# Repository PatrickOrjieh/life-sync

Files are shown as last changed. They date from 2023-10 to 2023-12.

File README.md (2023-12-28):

# Aerosense Project

## About Aerosense

Aerosense is a 3rd year Universal Design Project, focused at improving daily living for individuals with asthma through universal design principles. Moving from wearable to portable, Aerosense is an air quality monitor that provides real-time data, historical analytics, and health insights directly to users' smartphones.

## Features

- **Real-Time Monitoring**: Tracks PM2.5, PM10, VOCs, and other air quality measurements.
- **Portability**: Designed for on-the-go use without compromising functionality.
- **Mobile App**: Real-time data and historical trends.
- **Personalized Notifications**: (Buggy) Alerts tailored to individual health profiles.
- **Educational Content**: Understand the impact of air quality on health.
- **GPS Mapping**: Identify and avoid areas with poor air quality.

## Universal Design

The Aerosense project uses the principles of universal design, ensuring accessibility and ease of use for all users, regardless of age, ability, or asthma severity. We have conducted extensive user testing to refine the user interface and experience, making sure that the information is not only accessible but also actionable (future enhancements).

## User Testing and Evaluation
User testing was a crucial part of our development process. We used the think-aloud protocol, to gather  data on our system's usability and functionality. Our testers, including Seun (a first-year Business student with asthma),James and Tom , provided invaluable feedback that will directly influence the final design and features.

## Test Documentation
Our test documentation includes detailed test cases that cover both UI interactions and user experiences. We have recorded the testing process, issues encountered, and positive aspects noted by the testers.

## Project Code
The project code can be found in the link - `https://github.com/PatrickOrjieh/air-quality-monitor`

## Update to About Section

**Previous:**
"Universal design project focused on creating a wearable air quality monitor tailored for asthma patients. Integrates with a mobile app for real-time alerts and analysis."

**New:**
"A universal design project, Aerosense offers a portable air quality monitoring solution that helps individuals with asthma through actionable environmental insights, supported by an intuitive mobile application."

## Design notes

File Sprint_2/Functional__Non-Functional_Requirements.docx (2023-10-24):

Functional Requirements

1. Air Quality Measurement:
  - The device shall measure and detect particulate matter levels using the PMS7003 sensor.
  - The device shall measure volatile organic compounds and other harmful gases using the BME680 sensor array.

Still reconsidering the location addition at the moment.

2. GPS Integration:
  - The device shall identify and record the user's real-time location using the Neo 6m/Grove GPS.
  - It should timestamp air quality measurements with the respective GPS location.
3. User Alerts on the Wristband:
  - The wristband shall trigger a vibration and sound alert if detected air quality levels surpass predefined hazardous thresholds.
  - The wristband shall exhibit a light to indicate the severity of the air quality (green for good, yellow for moderate, red for poor).
4. Mobile Phone Notifications:
  - In the event of a hazardous air quality detection, a notification shall be sent to the connected mobile phone detailing the air quality measurements.
  - The mobile app shall display levels of particulate matter, VOCs, and maybe current GPS coordinates.
5. Data Storage:
  - Air quality measurements, timestamps, and locations for at least the previous 48 hours shall be stored on the mobile application.
  - Users shall have an option on the app to reset or clear this stored data.
6. Battery Status:
  - The mobile app shall display the current battery level of the wristband.
  - It should notify the user when the battery level goes below a certain threshold.

Non-Functional Requirements:

1. Usability:
  - The wristband should minimize physical interaction, with the mobile app serving as the primary interface for detailed information.
  - Alerts and notifications should be easily distinguishable and understandable.
2. Portability:
  - The device should be lightweight and comfortable for daily wear.
  - It should have a design that is aesthetically pleasing and suitable for various environments (work, sport, casual).
3. Battery Life:
  - The wristband should operate for at least 48 hours on a full charge, considering minimal interactions.
4. Accuracy:
  - Air quality measurements should have an error margin of less than 5%.
  - If using location then GPS coordinates should be accurate to within 10 meters.
5. Durability & Robustness:
  - The wristband should be resistant to everyday wear and tear.
  - It should be splash-proof to handle minor exposures to water.
6. Response Time:
  - The device should relay air quality measurements to the mobile app with a delay of no more than 5 seconds.
  - Alerts should be triggered on the wristband within 5 seconds of a hazardous threshold being detected.
7. Compatibility:
  - The wristband's connected app should be compatible with major mobile OS.
8. Scalability:
  - Future versions should allow for easy integration of additional sensors or features without a complete overhaul of the system.

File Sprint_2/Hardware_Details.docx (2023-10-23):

Sensor Research

PMS7003 - which detects particulate matter in the air which can detect particles of size PM10, PM2.5, PM1 and PM0.3. The PM5003 was rejected as it is too large to be considered for a wearable device. The ENS160 is smaller than the chosen sensor but only measured PM10 and PM2.5.

BME680 - senses VOCs (volatile total compounds) which contribute to air quality. The reviews for this were consistently high across a number of different websites. The SGP30 was also considered however the response time is 2s whereas the BME680 is 1s.

Air530 – location tracker which has low power usage and a good update rate between 1 and 10Hz. The Adafruit Ultimate GPS was a strong competitor with slightly lower power usage and the position accuracy was higher, however was over twice the price of the Air530. In an effort to keep the cost down the Air530 was chosen as it still provided a high tracking sensitivity and plenty of supporting documents.

Hardware Purchased | Price (excluding shipping & VAT)
PMS7003 | 23.05
BME680 | 21.77
Air530 | 12.56
Pi Zero 2 W | 19.58
Vibrating mini motor disc | 1.96
575 ultimate resistor kit | 6.91
Full size breadboard | 5.76
LDR 5 pack | 2.30
Female/male jumper wires | 1.96
Female/female jumper wires | 1.96
Male/male jumper wires | 1.96

Total: €99.77

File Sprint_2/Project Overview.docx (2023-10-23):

Wristband Air Quality Monitor for Asthma Patients

Executive Summary:

Urban living brings with it a lot of air pollutants. Our mission? To make a wrist worn gadget for asthma patients. This tool will gauge the surrounding air quality, providing them with real-time updates. It's more than just a device; it's about giving people the knowledge they need to dodge potential asthma attack.

Objective:

To design, develop, and test a wristband that monitors real-time air quality, providing asthma patients with alerts about environments that may trigger respiratory issues.

Background:

Ask anyone with asthma, and they'll tell you: certain pollutants can feel like invisible enemies. Having information on air quality would be of great benefit. With this wristband, we're not just offering data. We're offering peace of mind.

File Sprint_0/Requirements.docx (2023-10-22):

Functional Requirements:

1. Monitoring Heart Activity:

- The band should always track the wearer's heartbeat using a light-based sensor.
- An alert is necessary if the heart rate goes beyond a set limit, showing potential strain.

2. Tracking Oxygen Levels:

- The band needs to check the amount of oxygen in the user's bloodstream.
- Alerts should be sent if the oxygen count falls under a safe limit.

3. Personal Information Entry:

- Users can input details such as age, weight, height, and workout aims like losing weight, bulking up muscles.
- Using this info, the band or its paired app should suggest tailored exercises.

4. Instant Responses:

- Vibrations or on-screen notifications should be given by the band, depending on heart activity and oxygen counts.
- Messages like "Ease up", "Time for a short rest", or "Push just a bit harder" could be displayed.

5. Exercise Time Keeper:

- An in-built clock in the band should measure each exercise period.
- It's essential for users to have control over this clock: starting, pausing, as needed.

6. Syncing with Smartphone App:

- Bluetooth should link the band with an app on the phone.
- This app is meant to present a thorough breakdown, graphics, and past records sourced from the band.

Non-Functional Requirements:

1. User Experience:

- New users should find the band's layout natural and easy, with little to no help.
- The app must offer smooth browsing with a good design.

2. Powering the Device:

- In typical conditions, the band's battery should last a minimum of two days.
- A warning is vital when the battery is about to run out, specifically under 20%.

3. Craftsmanship and Endurance:

- Resistance to water and sweat is a must for the band.
- Regular fitness sessions shouldn't wear it out; it needs to be sturdy.

4. Safeguarding User Information:

- Encryption is essential for any user information in either the band or app.
- Adherence to data safeguarding regulations is crucial, guaranteeing that no data gets shared unless the user approves.

5. App Compatibility:

- The software working with the band should be operational on Android and iOS.

6. Quick Feedback:

- The band has to provide instantaneous advice, free from any noticeable holdup.
- The app must show the band's data promptly without undue waiting times.

7. Style:

- The design of the band should be contemporary and attractive to the intended users.
- Multiple options in terms of colors and designs would be a nice touch for users.

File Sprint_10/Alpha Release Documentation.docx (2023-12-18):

DUNDALK INSTITUTE OF TECHNOLOGY

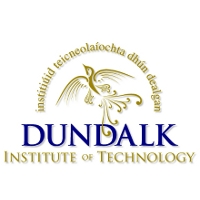
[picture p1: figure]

Alpha Release Technical Documentation On

AEROSENSE – SMART HUB FOR AIR QUALITY MONITORING

Project Carried Out

By

D00251785 PATRICK ORJIEH

D00244618 ROBERT NUGENT

D00261104 CONOR MC GINN

D00240060 HANNAH MC ELROY

Under the Supervision of

DR. JOHN LOANE

DEPARTMENT OF COMPUTING AND MATHEMATICS

SCHOOL OF INFORMATICS AND CREATIVE ARTS

DEPARTMENT OF VISUAL AND HUMAN-CENTRED COMPUTING

EXECUTIVE SUMMARY

The Alpha release of the Aerosense project represents a key phase in the development of our Smart Indoor Air Quality Hub. This initial release is a comprehensive prototype that demonstrates the capability of our system to assist individuals with asthma in monitoring the air quality within indoor environments.

Our system's architecture is detailed through clear diagrams that illustrate the interactions between the IoT components, the cloud-based web server, and the user interface. These diagrams serve to clarify the flow of data and the security measures in place to protect it.

The prototype, hosted on an AWS cloud server, showcases the core functionalities that will be present in the final product. It includes a working model of the IoT hardware, the software on the web server, and the database that stores and processes the gathered data. The use of PubNub ensures secure and efficient communication between the IoT devices and the web server.

We have taken significant steps to secure the application, with particular attention to the protection of data while it is stored and as it moves through the system. The security protocols we have implemented are critical in maintaining the privacy and integrity of user data.

The documentation for the Alpha release reflects the steps to creating a user-friendly and secure system. It outlines our approach to addressing the needs of asthma patients by providing them with actionable insights into their indoor air quality.

In summary, the Alpha release documentation shows the need of the Aerosense project and sets a clear direction for future development. It shows the first step to delivering a product that is of value to users, particularly those managing asthma in their daily lives.

## GLOSSARY

- Aerosense: A project aimed at developing a portable device (Smart Indoor Air Quality Hub) for monitoring indoor air quality, particularly beneficial for individuals with asthma.
- Smart Indoor Air Quality Hub: A portable device designed to provide real-time data and insights about indoor air quality, helping individuals, especially those with asthma, to understand and manage their environment better.
- PubNub: A cloud-based service that provides real-time data streaming and messaging solutions, used in Aerosense for real-time communication between the device and the server.
- AWS (Amazon Web Services): A comprehensive and widely adopted cloud platform that offers various services such as computing power, database storage, and content delivery. In Aerosense, it's used for data processing and storage.
- Alpha Prototype: An early version of a product that is functional enough to demonstrate the concept and design but may not have all the final features and polish of the final product.
- Cloud Server: Remote servers accessed over the internet used to store, manage, and process data, as opposed to a local server or personal computer.
- User Interaction: The process and experience of a person engaging with the Aerosense system, particularly through its mobile application.
- Sensor Data Acquisition: The process of collecting data from various sensors (like those measuring air quality) used in the Aerosense system.
- Raspberry Pi: A small, affordable computer used for various programming and electronics projects. In Aerosense, it serves as the central unit for collecting sensor data.
- PMS7003 Particle Sensor: A sensor that measures particulate matter (PM) in the air. It's crucial for providing data on air quality, especially for asthma patients.
- BME680 Sensor: This sensor provides a range of environmental data, including temperature, humidity, and volatile organic compounds (VOCs), which are chemicals that can affect air quality.
- Grove Air 530 GPS Sensor: A sensor used for determining geographical location, enabling the Aerosense system to tag air quality readings with specific locations.
- PubNub: A cloud-based service that provides real-time data communication between devices and servers. It's used in Aerosense for transmitting sensor data from the Raspberry Pi to the cloud server.
- PubNub Access Keys: Unique identifiers used for secure access to PubNub's publish and subscribe channels, ensuring that only authorized devices and servers can communicate through the platform.
- AWS Cloud: Amazon Web Services Cloud, a cloud computing platform that hosts the server for the Aerosense system. It's responsible for data processing and storage.
- AES-256 Encryption: A method of encrypting data to protect it from unauthorized access. It's used in Aerosense to secure data at rest in the database.
- TLS Protocol: Transport Layer Security protocol, a method for encrypting data during transmission to prevent interception by unauthorized parties. Used in Aerosense for secure data transfer.
- Firebase Authentication: A Google service that provides user authentication for applications. In Aerosense, it manages user login processes and secures access to user data.
- Google OAuth: An authentication method provided by Google that allows users to log in to applications securely using their Google account.
- Mobile Application: The user interface of the Aerosense system, available on smartphones. It displays air quality data and allows users to interact with the system.
- Community Data Sharing: A feature in Aerosense where users can share anonymized environmental data to contribute to broader air quality studies.
- GDPR (General Data Protection Regulation): A regulation in EU law on data protection and privacy. In Aerosense, it's referenced to highlight the system's compliance with data privacy laws.
- Power Bank: A battery pack that provides electricity to the Raspberry Pi so it can work without being plugged into a wall.
- Breadboard: A board for making an electrical circuit without soldering, useful for testing parts of a circuit.
- Vibrating Motor Disc: A small disc that shakes to give a physical alert when the air quality changes.
- LED Indicator: A light that changes color to show different air quality levels.
- Buzzer: A device that makes a beeping sound when the air quality reaches a level that could be concerning.
- USB to UART Converter: A tool that lets the Raspberry Pi talk to the sensors using USB ports, which are very common on computers (TX & RX).
- Wiring: Cables that connect different parts of the electrical circuit in the diagram, each with a different color for easy identification.
- Flask: A lightweight web application framework written in Python, used for creating the web server in the Aerosense project.
- Cron Job: A scheduled task in Unix-like operating systems. In Aerosense, it's used to periodically trigger data collection from the sensors.
- Encryption: The process of converting information or data into a code to prevent unauthorized access. Used in Aerosense to secure data transmission.
- HTTPS (Hypertext Transfer Protocol Secure): An extension of HTTP used for secure communication over a computer network. In Aerosense, it's used for secure communication between the client application and the server.
- Database Schema: The structure of a database system, described in a formal language. In Aerosense, it defines the structure of the MySQL database.
- Real-time Data Transfer: The process of continuously transferring data as it's collected without delay. In Aerosense, this is facilitated by PubNub.
- API (Application Programming Interface): A set of protocols for building and interacting with software applications. Aerosense uses APIs to enable communication between different components of the system.
- Volatile Organic Compounds (VOCs): Organic chemicals that have high vapor pressure at room temperature and can affect air quality. Measured by the BME680 sensor in Aerosense.
- MySQL: An open-source relational database management system. In Aerosense, it's used to store and manage data.
- AWS EC2 (Amazon Web Services Elastic Compute Cloud): A web service that provides resizable compute capacity in the cloud, used to host the server for Aerosense.

## LIST OF TABLES AND DIAGRAMS

### List Of Tables

### List Of Diagrams

Diagram 1: System Architecture Diagram of Aerosense Application…................................... 8

Diagram 2: Updated Fritzing Diagram: Sensor Connections with Pi .....................................11

## 1. INTRODUCTION

The Aerosense project is an initiative designed to offer an innovative solution to air quality monitoring, specifically addressing the needs of individuals with asthma. The project aims to develop a portable "Smart Indoor Air Quality Hub" that provides real-time insights into indoor air quality, which is crucial for people who suffer from respiratory conditions.

This documentation outlines the development process, architecture, and functionalities of the Aerosense system. It details the collaborative effort put forth to design a system that combines sensor data acquisition, cloud-based processing, and user interaction through a mobile application.

Our goal is to create a system that is user-friendly, aligning with our educational objectives and the practical needs of asthma patients. The project leverages the capabilities of the Raspberry Pi as a data collection point, PubNub for real-time communication, and AWS cloud services for data processing and storage.

The other sections will provide an overview of the system architecture, describe the alpha prototype, discuss security measures, demonstrate the deployment on a cloud server.

As the developers of Aerosense, we have committed ourselves to a practical and simplified approach, ensuring that the end product is not only functional but also accessible to our target users. We believe that the integration of real-time environmental data with health management tools can significantly improve the daily lives of asthma patients, and this belief has been the driving force behind our project as well as the academic part.

## 2. SYSTEM ARCHITECTURE

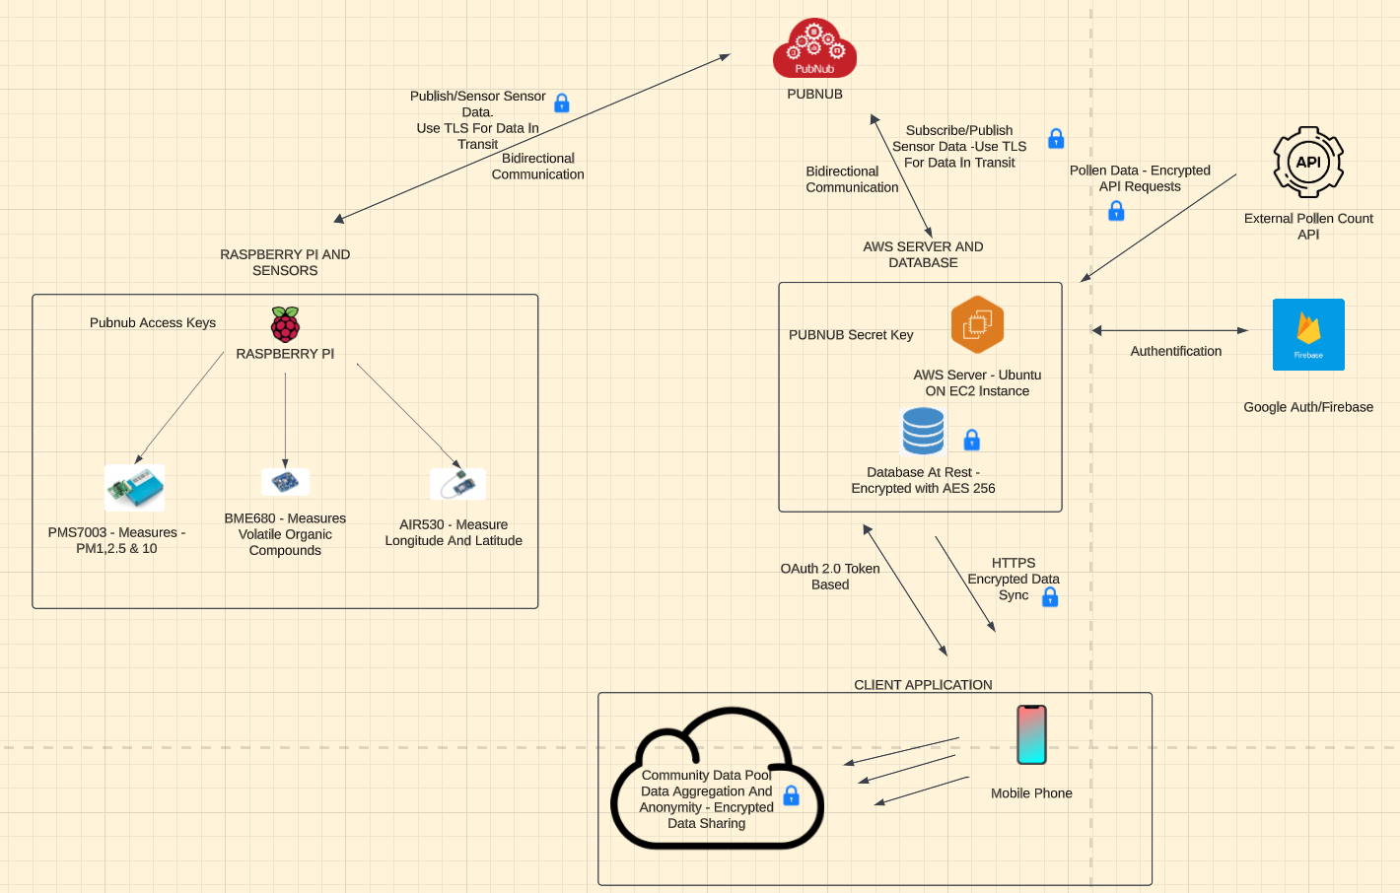
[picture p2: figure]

Diagram 1: System Architecture Diagram of Aerosense Application

### Overview

The Aerosense project's system architecture is a comprehensive framework designed to monitor and analyse air quality, tailored specifically for asthma patients. This architecture integrates various technologies including Internet of Things (IoT) devices, cloud computing, real-time data communication, and a mobile application interface.

### IoT Elements

The core of the Aerosense system is based around a Raspberry Pi, which acts as the central data collection unit. Attached to the Pi are three crucial sensors:

1. PMS7003 Particle Sensor: This sensor is responsible for measuring particulate matter in the air, providing data on air quality that is particularly relevant to asthma sufferers.
2. BME680 Environmental Sensor: Offers a broader range of environmental readings including temperature, humidity, and volatile organic compounds (VOCs).
3. Grove Air 530 GPS Sensor: Used to provide location data, enabling tagged air quality readings, which is essential for mapping and analysing environmental conditions in different areas.

### Data Communication via PubNub

Data from these sensors is transmitted using PubNub, a real-time communication platform. The Raspberry Pi publishes the sensor data to a dedicated PubNub channel, which is then subscribed to by the cloud server. This setup ensures the delivery of data from the sensors to the server for processing.

To secure this communication:

- PubNub Access Keys: Unique access keys are used for both publishing and subscribing to the data, ensuring that only authorized devices and servers can access the communication channel.
- Bidirectional Communication: Certain scenarios allow for two-way communication between the cloud server and the Raspberry Pi, facilitating real-time updates and commands.

### Cloud Server and Database

The server hosted on AWS Cloud forms the backbone of data processing and storage. It subscribes to the PubNub channel to receive sensor data, processes this data according to predefined processing algorithms that will be made by us, and stores it in a secure database. The database maintains records of air quality readings, user profiles, and other relevant data.

For securing data:

- At Rest: The database employs encryption mechanisms like AES-256 to secure data at rest.
- In Transit: Data transferred between the IoT devices, server, and the mobile application is encrypted using TLS protocols by PubNub, ensuring secure data transmission.

### Firebase Authentication

User authentication is managed by Firebase, which integrates Google OAuth for a secure and convenient login process. Firebase provides authentication tokens that are used to verify user identity and secure access to the mobile application and personal data.

### Mobile Application

The client-side of the Aerosense system is a mobile application that serves as the user interface. It allows users to view real-time air quality data, receive alerts, and manage their profiles. The app fetches data from the cloud server, user interactions with the app are also sent back to the server for processing and response.

### Community Data Sharing

One of the innovative features of Aerosense is its community data sharing aspect. Users can choose to share anonymized environmental data, contributing to a broader understanding of air quality trends. This data is coupled by the server and can be accessed for public awareness purposes.

### Conclusion

The Aerosense system architecture has been designed to ensure a flow of data from the sensors to the end-user. Security protocols are in place at every step to protect sensitive information, especially considering the health-related nature of the data (GDPR).

### Fritzing

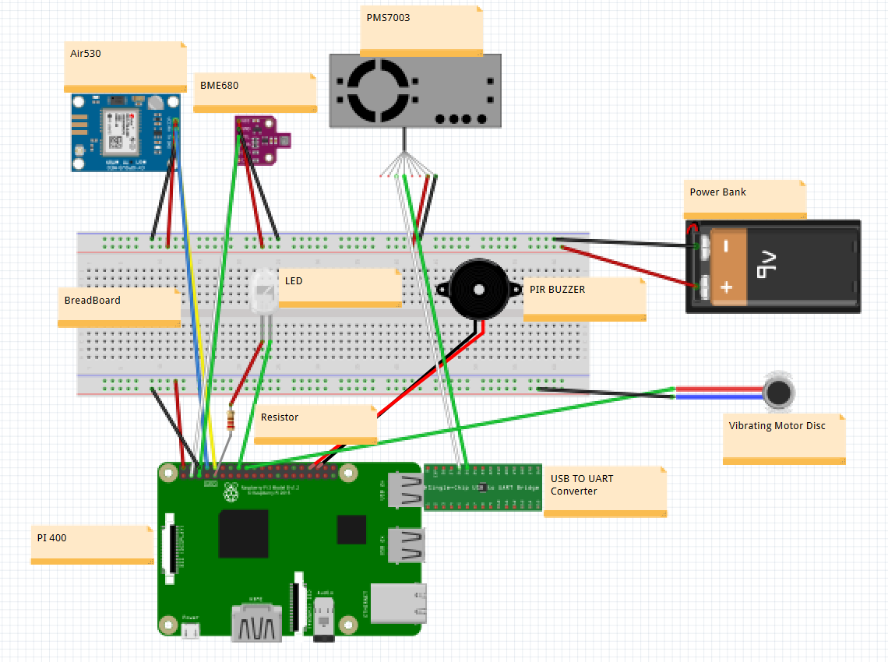
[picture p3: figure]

Diagram 2: Updated Fritzing Diagram: Sensor Connections with Pi

Fritzing Diagram Description for Aerosense Project

The Fritzing diagram provides a visual representation of our Aerosense hub's electronic setup. This setup is crucial for monitoring air quality and ensuring the system is interactive and responsive to the environment it monitors.

1. Raspberry Pi 400: The heart of our project, the Raspberry Pi 400, serves as the microcontroller that processes data from the attached sensors. It also acts as the communication bridge between the sensors and our cloud services.
2. Power Bank: A portable power bank supplies electricity to the Raspberry Pi, ensuring that our hub remains switched on even without a direct power outlet. This helps the portability of our device.
3. Breadboard: We've used a breadboard for mounting the electronic components. This allows for a modular and non-permanent setup, making it easy to test the system.
4. PMS7003 Particle Sensor: This sensor detects particulate matter (PM) levels in the air, crucial for assessing air quality. The sensor's data output is sent to the Raspberry Pi.
5. BME680 Sensor: The BME680 provides comprehensive environmental readings, including humidity, temperature, and VOCs. These factors are vital for a good understanding of indoor air quality, particularly for users with asthma.
6. Grove Air 530 GPS Sensor (Air530): This GPS module provides geolocation data, enabling our system to tag air quality measurements with precise locations. This feature is key for tracking and analysing environmental conditions across different indoor settings.
7. Vibrating Motor Disc: Added for haptic feedback, the vibrating motor disc, offers an alert option alongside the buzzer and notification. This ensures all users receive prompt notifications regarding air quality changes.
8. LED Indicator: The multi-color LED indicator displays real-time air quality status. It's connected through a resistor to the GPIO pin on the Raspberry Pi to manage voltage and current flow, ensuring the LED operates safely.
9. Buzzer: The buzzer serves as an audible alert mechanism, making a sound when air quality thresholds are reached. It's also connected to a GPIO pin and programmed to trigger alongside the LED indicator.
10. USB to UART Converter: This converter is critical for serial communication between the Raspberry Pi and the sensors that require UART (TX & RX) communication. It facilitates the transfer of sensor data to the Raspberry Pi for processing.
11. Wiring: The diagram shows all necessary wiring connections, including power lines, ground connections, and data lines. Each wire is color-coded for easy identification of the circuit flow.

## 3. Alpha Prototype Documentation

### Introduction

This section shows the development and features of our alpha prototype for the Aerosense project. Our prototype integrates Internet of Things (IoT) hardware, a web server hosted on AWS, and PubNub communication for real-time data transfer. We've focused on building a system that demonstrates the core parts of aerosense.

### Hardware

For the IoT hardware, we chose to use the BME680 sensor and the PMS7003 particulate matter sensor. However, during development, we encountered a challenge with the PMS7003 sensor, due to an incompatible IDC adapter. Now, our current prototype primarily relies on the BME680 sensor, which measures air quality, temperature, humidity, and gas resistance.

Our approach has been to keep the hardware setup as simple as possible while ensuring reliable data collection. The BME680 sensor connects to a Raspberry Pi, serving as our primary data collection point. The Raspberry Pi is programmed to periodically read sensor data, preparing it for transfer to our web server.

### Webserver

The core of our prototype is a Flask-based web server. This server is responsible for handling requests from both the IoT hardware and the client application. It processes incoming sensor data, interacts with the database, and manages user requests.

The web server's primary functions include:

- Receiving encrypted sensor data from the IoT devices.
- Decrypting and processing this data for storage.
- Serving processed data to the user interface upon request.
- Handling user authentication and session management.

### Hosted on AWS

Our web server is hosted on Amazon Web Services (AWS), The domain https://www.aerosense.life is custom-configured to point to our AWS-hosted server, offering a the needed endpoints for out project.

### PubNub Communication

For real-time data transfer between the IoT devices and the server, we employed PubNub. PubNub is efficient and reliable to offer real-time messaging system. Our implementation uses PubNub to:

- Securely transmit encrypted sensor data from the Raspberry Pi to the server.
- Enable real-time updates in the client application, particularly for live air quality readings.
- User can change the settings of the Hub as well.

The server runs a background task that constantly listens for incoming data on the PubNub channel, ensuring that new sensor readings are immediately captured and processed.

### Database

We are using a MySQL database hosted on the same AWS server. This database stores user data, sensor readings, asthma profile and settings. Our database schema is designed to efficiently store and retrieve data.

Key aspects of our database implementation include:

- Tables for user data, sensor readings, and device configurations.
- Efficient indexing to speed up queries, especially for retrieving the latest sensor data.
- Secure storage of user credentials and personal data.

### Security

Given the sensitivity of user data and the potential dangers in IoT systems. Our security measures include:

- Encryption of data transmitted between the IoT devices and the server.
- Secure handling and storage of user credentials using Firebase.
- Implementation of HTTPS for secure communication between the client application and the server.

## 3. Cloud Server Description

Our Aerosense project uses a cloud server hosted on Amazon Web Services (AWS), which handles various aspects of the system. This server plays a role in processing, storing, and managing data received from IoT devices and user interactions. Below is a detailed overview of our cloud server's functionalities and the endpoints implemented:

### Endpoints

- / (Root Endpoint): This endpoint serves a simple purpose: when accessed, it returns a "Hello, World!" message. This was primarily created for initial testing to ensure that our server setup was successful and responding to HTTP requests.
- /api/register: This endpoint is integral for user registration. It leverages Firebase for secure and efficient user authentication. When a new user registers through our mobile application, this endpoint processes the registration data, creating a new user record in Firebase and our MySQL database.
- /api/login: While we have implemented this endpoint, it's mainly redundant due to the Android SDK handling user logins. However, it exists as a part of our backend architecture for potential future use or alternative login methods.
- /api/home: One of the most important endpoints, /api/home, is responsible for delivering real-time air quality data to the user's dashboard. When accessed, it retrieves the latest sensor measurements from the database and provides insights into the current air quality, indicating whether it's good, moderate, or poor.
- /api/settings: This endpoint allows users to view and modify their settings. Additionally, it enables users to adjust their Smart Indoor Air Quality Hub settings, like toggling alerts or changing measurement intervals.

## 4.PubNub

In our project, we have implemented PubNub for real-time data communication, which is essential for transmitting sensor data and user settings:

- Aerosense Channel (aerosense_channel): This channel is the backbone of our real-time data transmission. The Raspberry Pi, equipped with the BME680 sensor, sends the collected air quality data to this channel. Our server, constantly listening to this channel, receives the data, decrypts it, and stores it in the database for further processing and access via the /api/home endpoint.
- User Settings Channel (user_settings_channel): This channel facilitates the real-time update of user preferences. When a user modifies settings in the app, the changes are sent to this channel. Our server listens to this channel, updates the user's settings in the database, and ensures that these preferences are reflected in the operation of the Smart Indoor Air Quality Hub.

## 5.Security Implementation in the Aerosense Project

### IoT Device Security:

Our IoT device, primarily the Raspberry Pi equipped with a BME680 sensor, we implemented a software-level security by regularly updating the Raspberry Pi's operating system and software packages, ensuring protection against vulnerabilities.

### Access to Communication Channels:

We utilized PubNub for real-time data communication between the IoT device and the server. PubNub inherently employs TLS (Transport Layer Security) protocols, ensuring the encryption of data in transit.

The unique PubNub publish and subscribe keys ensure that only our authorized devices and server can access the designated communication channels.

### Database Security:

Our MySQL database, hosted on AWS, is protected within a secured environment. We have configured AWS security groups to allow access only from specific IP addresses and ports, effectively guarding against unauthorized entry.

Database access credentials are managed securely, and limited access rights, ensuring that only essential services and personnel can access the database.

### Webserver Security:

The webserver, also hosted on AWS, operates under HTTPS, which encrypts data between the client application and the server, safeguarding against data interception and tampering.

### Data in Transit Security:

For data transmission, we use HTTPS and TLS protocols to encrypt data sent from the IoT device to the server and vice versa, ensuring secure data in transit.

Our implementation of cipher encryption for PubNub messages adds an additional layer of security, ensuring that the sensor data remains confidential during transmission.

### Firebase Security:

We incorporated Firebase for user authentication and management. Firebase Authentication provides secure handling of user credentials and sessions.

Firebase's security rules ensure that only authenticated and authorized users can access their respective data, thereby enhancing the overall security of our system.

## 6.Future Enhancements for the Aerosense Project

As we reflect on Aerosense project, we are planning several exciting enhancements for our next part of the project. These improvements aim to better the functionality, user experience, and data accuracy. Here's a list of potential upgrades we are considering:

1. Speaker Integration for the Raspberry Pi: To enhance the user experience, especially during critical air quality alerts, integrating a speaker with the Raspberry Pi would be highly beneficial. This addition would allow the system to not only visually indicate poor air quality levels but also audibly alert users with specific recommendations or warnings.
2. Dedicated Raspberry Pi 4: Upgrading to a Raspberry Pi 4 would offer increased processing power and efficiency. Unlike the Pi 400, which includes an integrated keyboard, a dedicated Pi 4 would be more suitable for our compact and portable design requirements.
3. IDC Adapter for the PMS7003 Sensor: To resolve the compatibility issues we faced with the PMS7003 particulate matter sensor, getting the correct IDC adapter is essential. This will enable us to integrate the sensor effectively and enhance our system's capability to measure particulate matter.
4. New GPS Sensor: Our experience with the Air530 GPS sensor highlighted some data reading challenges. To address this, we plan to research and invest in a more reliable and accurate GPS sensor. This upgrade will ensure precise location tagging for our air quality measurements.

## CONCLUSION

The Aerosense project shows innovation in indoor air quality monitoring, particularly for individuals with asthma. Combining IoT technology, cloud computing, and real-time data communication, we have developed a comprehensive system that offers valuable insights into air quality. Our approach focused on integrating reliable hardware (like the BME680 sensor), secure and efficient software solutions (including Flask, PubNub, and Firebase), and AWS.

## REFERENCES:

1. PubNub Official Documentation: https://www.pubnub.com/docs
2. Firebase Documentation: https://firebase.google.com/docs
3. Flask Web Framework: https://flask.palletsprojects.com/en/1.1.x/
4. BME680 Sensor Overview: https://www.bosch-sensortec.com/products/environmental-sensors/gas-sensors-bme680/
5. Raspberry Pi Documentation: https://www.raspberrypi.org/documentation/
6. MySQL Database Documentation: https://dev.mysql.com/doc/
7. General Data Protection Regulation (GDPR) Compliance: https://gdpr-info.eu/

WRISTBAND AIR QUALITY MONITOR – VERSION 1

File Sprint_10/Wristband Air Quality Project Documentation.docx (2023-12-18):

DUNDALK INSTITUTE OF TECHNOLOGY


Technical Documentation On

WRISTBAND AIR QUALITY MONITOR

Project Carried Out

By

D00251785 PATRICK ORJIEH

D00244618 ROBERT NUGENT

D00261104 CONOR MC GINN

D00240060 HANNAH MC ELROY

Under the Supervision of

DR. JOHN LOANE

DEPARTMENT OF COMPUTING AND MATHEMATICS

SCHOOL OF INFORMATICS AND CREATIVE ARTS

DEPARTMENT OF VISUAL AND HUMAN-CENTRED COMPUTING

EXECUTIVE SUMMARY

In the context of our Universal Design Project, we - the LifeSync team - embarked on an innovative journey that led to the birth of "Aerosense." Imagine a wristband that does more than tell time; it gives you a real-time snapshot of the air you breathe. With the surge of pollution in our cities, it`s high time we have something that keeps us informed. That's where Aerosense comes into play.

This isn't just about tech for the sake of tech. By leveraging the latest IoT, we've merged the handiness of everyday wearables with cutting-edge sensors that monitor air quality with finesse. It's all rooted in Universal Design's philosophy, aiming to make air quality data not just available but effortlessly integrated into our routines.

Dive into this report, and you'll discover the ins and outs of Aerosense's design, the strategies we employed, and the hurdles we overcame. For us at LifeSync, this wristband isn't just a gadget; it encapsulates our dedication to creating solutions that genuinely enrich our lives.

## GLOSSARY

- Aerosense: The brand name of the air quality wristband.
- IoT: Internet of Things - Refers to the network of physical objects embedded with sensors, software, and other technologies to connect and exchange data with other devices over the Internet.
- API: Application Programming Interface - A set of tools and protocols that allow different software applications to communicate with each other.
- Asthma: A respiratory condition marked by spasms in the bronchi of the lungs, causing difficulty in breathing. It is often connected to allergic reactions or other forms of hypersensitivity.
- GPIO (General Purpose Input/Output) pins: Pins on the Raspberry Pi used for connecting and communicating with external devices.
- ADC (Analog to Digital Converter): A device that converts analogue signals (continuous values) to digital values.
- Particulate Matter: Tiny particles or droplets in the air that are two and one-half microns or less in width.
- AQI (Air Quality Index): A measure used to show how polluted the air currently is or how polluted it is forecast to become.
- VOC (Volatile Organic Compounds): Organic chemicals that have a high vapor pressure at room temperature. Their high vapor pressure results from a low boiling point, which causes large numbers of molecules to evaporate from the liquid or solid form of the compound and enter the surrounding air.
- PMS7003: A sensor that measures particulate matter of different sizes: PM10, PM2.5, PM1, and PM0.3.
- BME680: A gas sensor array used to measure VOCs, which impact air quality.
- Air530: A GPS sensor used to capture latitude and longitude for correlation with air quality measurements.
- Cron: A time-based job scheduler in Linux operating systems. Cron is used to schedule jobs (commands or scripts) to run periodically at fixed times, dates, or intervals.

## LIST OF TABLES AND DIAGRAMS

### List Of Tables

Table 1: Hardware Components Required for Aerosense Development .......................... 7

Table 2: User Information and Details ............................................................................ 12

Table 3: Wristband Specifications and Details ............................................................... 12

Table 4: Air Quality Measurement Data .......................................................................... 13

Table 5: User Location.................................................................................................... 13

Table 6: Notification Details ............................................................................................ 13

### List Of Diagrams

Diagram 1: Fritzing Diagram: Sensor Connections with Pi .................................................... 9

Diagram 2: Database Schema for Aerosense ...................................................................... 12

Diagram 3: User Registration and Login Page Design ........................................................ 17

Diagram 4: Reset Password Page Design ........................................................................... 18

Diagram 5: Home Screen Page Design ............................................................................... 18

Diagram 6: Menu Navigation Page Design .......................................................................... 19

Diagram 7: Location Display Page Design ........................................................................... 19

Diagram 8: History and Past Data Page Design .................................................................. 20

Diagram 9: User Settings and Configuration Page Design ………………………................ 21

## 1. INTRODUCTION

### 1.1 Purpose

In today's rapidly urbanizing world, the quality of air we breathe is a growing concern, particularly for vulnerable groups such as asthma sufferers. To address this challenge, we've initiated the development of the "Aerosense Wristband." This innovative wristband is specially designed to monitor air quality, catering specifically to those with asthma. With it, users can access immediate updates on the surrounding air quality, enabling them to make decisions that prioritize their health.

### 1.2 Significance

The idea behind the Aerosense Wristband was not just to create a new tech gadget. There's a genuine, urgent need for such a device. Several research studies have shown a clear correlation between declining air quality and an increase in asthma-related issues. With the Aerosense Wristband, we aim to empower users with the knowledge they need to avoid potential asthma attacks, ensuring they're not caught off guard. On a broader scale, by collecting data from numerous Aerosense devices, we might be able to identify specific areas with high pollution levels, as well as detect patterns over time. This could prove invaluable for those in roles ranging from city planning to healthcare policy development.

As we worked on the Aerosense Wristband, we focused on integrating the latest air quality sensing technology while keeping the user interface simple and intuitive. We strived for a sleek design, making sure that whether you're a tech enthusiast or just someone looking for a solution, the device is easy to use. This report will delve deeper into our development process, discussing everything from our initial feasibility studies to the depth of data management.

To make this report as reader-friendly as possible, we've avoided unnecessary technical jargon. Where complex ideas arise, we've tried to simplify them with relatable analogies and, when needed, included diagrams for a clearer understanding.

## 2. HARDWARE

### 2.1 Hardware Components Required for Aerosense Development:

Component | Description
Raspberry Pi 400 | Central processing and connectivity module.
Female/Female Jumper Wires | Connects sensors to the Raspberry Pi.
PMS7003 | Particulate Matter sensor to measure air quality.
BME680 | Measures air quality, temperature, humidity, and pressure.
Air530 | GPS Module to provide location data for air quality readings.
Vibrating mini motor disc | Alerts users to significant changes in air quality.
LDR Light dependent resistor | Measures light intensity for sleep mode.
MCP 3008 ADC | Analog to Digital Converter; works with the LDR.
Resistor kit | Various resistors to ensure proper voltage across circuits.
Full size breadboard | For testing and connecting various components.
Female/Male Jumper Wires | For flexible connections during prototyping.
Power bank | Portable power source for Aerosense when unplugged.

Table 1: Hardware Components Required for Aerosense Development

### 2.2 Hardware Overview

The primary objective of the Aerosense Wristband project is to develop an advanced air quality monitoring system made specifically for asthma patients. The primary component of this undertaking is the precise and efficient hardware design.

At the core of our hardware parts is the Raspberry Pi 400. This minicomputer acts as the central processing unit, interpreting and analysing data from various sensors. It’s very essential for our needs.

For the accurate assessment of air quality, we have added two specialized sensors: the PMS7003 and BME680. The combination of these sensors ensures comprehensive and precise data on particulate matter, volatile organic compounds, and other air quality metrics pertinent to asthma patients.

Geographical location is essential in understanding air quality patterns. The inclusion of the Air530 GPS module provides users with real-time location data, allowing them to know specific zones with bad air quality. This feature is useful for users to make informed decisions about their daily routes and routines.

User feedback is equally important. Rather than giving the user raw numerical data, the Vibrating mini motor disc and coloured LED serves as a tactile alert mechanism. In instances of deteriorating air quality, the device will vibrate.

Connection between the Raspberry Pi and the sensors is achieved using jumper wires, breadboards, and connectors. Power considerations led us to select a power bank. For real-time data retrieval and cloud-based analyses with AWS, internet connectivity is provided via the Raspberry Pi's inbuilt Wi-Fi capabilities.

### 2.3 Hardware Connectivity

To illustrate the connectivity of the components, the Fritzing tool would be used to generate the diagram.

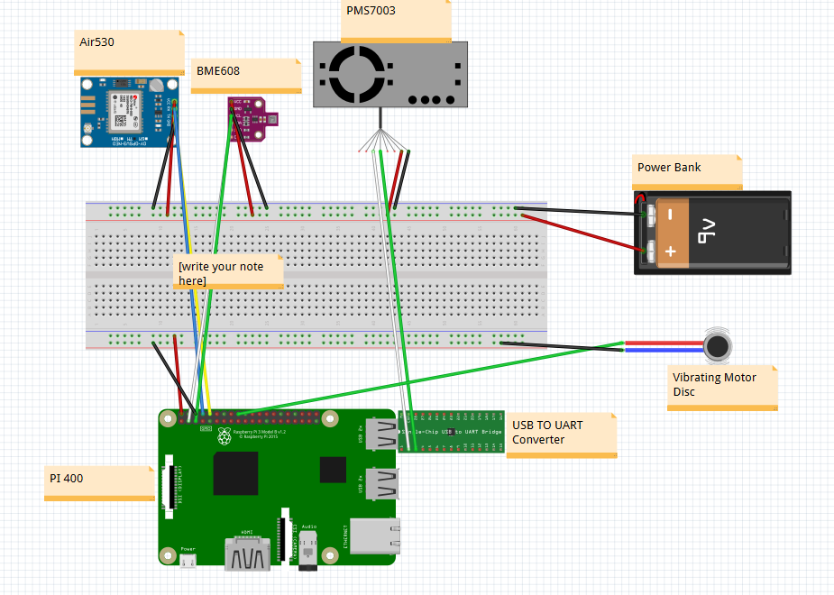
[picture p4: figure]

Diagram 1: Fritzing Diagram: Sensor Connections with Pi

- The Raspberry Pi 400 serves as the central unit connecting all sensors and modules.
- PMS7003 and BME680 sensors connect to the Raspberry Pi via GPIO pins using Female/Female Jumper Wires.
- Air530 GPS Module connects to the Raspberry Pi to fetch and log location data, helping users identify pollution hotspots.
- Vibrating mini motor disc gets activated when the sensors detect air quality levels beyond a predefined threshold.
- The LDR works in tandem with the MCP 3008 ADC to measure light intensity, which could help in activating a sleep mode for the wristband during low light conditions, thus conserving battery.
- The Resistor kit will be used to ensure that the correct voltage is applied across circuits, especially when connecting LEDs or buzzers.

### 2.4 Power And Internet Connectivity

The Aerosense Wristband will primarily be powered by a power bank, making it portable and user-friendly. This ensures that the device can continuously monitor air quality without being connected to a fixed power source. The Raspberry Pi 400's built-in Wi-Fi capabilities will be leveraged for internet connectivity. This allows the device to upload air quality data to a server and fetch updates if necessary.

## 3. DATA

### 3.1 Data Gathering

a. Particulate Matter Measurements:

Sensor Utilized: PMS7003
Measurements Captured:

- PM0.3
- PM1
- PM2.5
- PM10

The measurements for PM2.5 and PM10 will be critical since there are standard AQI calculations for these. The PM2.5 and PM10 values provide insights into smaller particles that can be inhaled and pose health risks.

b. Volatile Organic Compounds (VOC) Measurements:

Sensor Utilized: BME680
The BME680 sensor measures the concentration of VOCs in the air. High levels of VOCs can indicate polluted air, often resulting from chemicals or other pollutants.

c. GPS Measurements:

Sensor Utilized: Air530
This sensor captures the geographical location (latitude and longitude) where air quality measurements are taken. This allows users to identify specific locations with good or poor air quality.

### 3.2 Data Storage

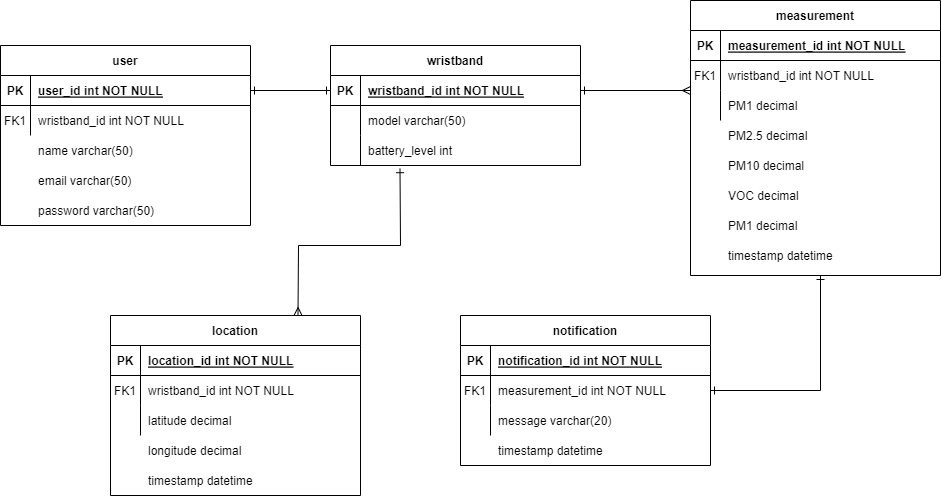
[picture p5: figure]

Diagram 2: Database Schema for Aerosense

- An SQL file is added in the git repo that will have the create statements for the Database

For storing the data gathered, MySQL relational database will be utilized. The following are the tables with their associated attributes:

a. User Table:

- userID: Unique identifier for the user.
- name: Name of the user.
- email: Email address of the user.
- password: Hashed password for authentication.
- wristbandID: Foreign key referencing the Wristband table.

Table 2: User Information and Details

b. Wristband Table:

- wristbandID: Unique identifier for the wristband.
- model: Model name or number of the wristband.
- batteryLevel: Current battery level percentage.

Table 3: Wristband Specifications and Details

c. Air Quality Measurement Table:

- measurementID: Unique identifier for the measurement.
- wristbandID: Foreign key referencing the Wristband table.
- PM1: Measurement for PM1 particles.
- PM2.5: Measurement for PM2.5 particles.
- PM10: Measurement for PM10 particles.
- VOC: Measurement for VOCs.
- timestamp: Time when the measurement was taken.

Table 4: Air Quality Measurement Data

d. Location Table:

- locationID: Unique identifier for the location entry.
- wristbandID: Foreign key referencing the Wristband table.
- latitude: Latitude of the location.
- longitude: Longitude of the location.
- timestamp: Time when the location was recorded.

Table 5: User Location

e. Notification Table:

- notificationID: Unique identifier for the notification.
- measurementID: Foreign key referencing the Air Quality Measurement table.
- message: Content of the notification.
- timestamp: Time when the notification was triggered.

Table 6: Notification Details

### 3.3 Data Processing

The data processing section shows how frequently the data will be collected, then processed and converted into meaning data for the user.

- Frequency of Data Collection and Processing:

Given the dynamic nature of air quality, data from sensors will be collected and processed every minute.

2. Using Cron for Automated Data Collection and Processing:

Cron will be set up to execute scripts that handle data collection and processing tasks.

  1) * * * * * sensor_data_collection.py
  2) * * * * * data_processing.py

3. After Data Is collected during the processing we have a detailed way we will convert the data into bad or good air quality, Using method in the data_processing.py in the git link.
- Extract the latest readings of PM10, PM2.5, and VOC from the database.

- Compute the AQI value for each pollutant type (PM10, PM2.5, VOC) based on predefined AQI conversions.

- Choose the highest AQI value among the measurements as the overall AQI for that minute.

- After processing, save the computed AQI and the percentage score back into the database. This transformed data will then be accessed by the user interface to provide real-time feedback.

4. Alerting Mechanism:

If the computed AQI reaches a threshold that indicates poor air quality, an alerting mechanism will be activated, notifying users to take appropriate action.

## 4. SECURITY AND PRIVACY

### 4.1 Device Security

The first feature that we will be implementing in order to support device security is a 4-digit pin for the device. When first using the wristband, the user will be prompted to setup a 4-digit PIN which will be used in the future to gain access to the device when attempting to connect to it. This will prevent anyone from connecting to the device and tampering with it.

To build on the security of this PIN, we will also implement a device lockout system. Whenever the user enters the PIN incorrectly 5 times then the device will be locked and not allow any access to it until the lock is lifted. When the device becomes locked, an email will be sent to the email address associated with the device with an option to unlock the device. By using this system. It will prevent unauthorized users to have an infinite number of tries at bypassing the PIN to access the device.

Another feature that we are designing that will increase the level of security for the device is a way for the user to remotely wipe or lock the device if they lose it. Once the device becomes lost, it will be vulnerable if found by someone else. To counter this, we will allow the user to lockdown their lost device from their current location using the app so that no one will be able to access it and tamper with it. As well as this, the user could wipe all of their data from the device and essentially reset it so that if someone would gain access to it, they wouldn’t be able to see any of their data.

### 4.2 Data in transfer security

The main way that we are going to keep data safe in transfer is through end-to-end encryption. This means that the data will be encrypted before it is transmitted and will only be decrypted once it has reached its destination. There are a lot of different ways to do this but the way which we plan on doing it is through the use of a strong encryption algorithm called AES, which stands for Advanced Encryption Standard. We have decided to use this specific algorithm as it is considered highly secure and efficient which will highly contribute to the overall security and performance of the system.

Another way to improve the security of the data is by carrying out data integrity checks. To ensure that the data was not messed with during transfer, we must check the integrity of the data once it is received by the server. We can do this by using cryptographic hashes. When the data is hashed using a hash function, a hash value is produced. This value will be sent with the data to the server so that the server can compare the received hash value with the one that it gets from carrying out the hash function itself. If the hash values match, then the data has not been messed with, otherwise, the data isn’t the same as what was originally sent.

Finally, we will make use of tokens during data transfer for authentication reasons. Tokens are important for authenticating the users who will be carrying out these data transfers. By using tokens, we can ensure that the user has appropriate permissions to carry out what they are trying to do as well as determine if they are a valid user or not. If the token hasn’t expired and is has been verified, then the action relating to data transfer will be performed.

### 4.3 Data in storage

While in storage, we will be encrypting data to make it more secure. It’s important that we encrypt personal data such as emails and passwords as we don’t want such information to end up leaked or stolen. Other than specifically encrypting, we can keep some of the data secure using methods such as password hashing and salting.

Another way of keeping the data safe while in storage is by enforcing strict access control. By using access control, we only allow certain authenticated users access to the data and decide which of these users will be able to modify this data. We will only allow each user the exact permissions that they will need to carry out their task and nothing more than that. We will be basing the access control on user roles so that each user has the appropriate permissions for their role and responsibilities.

We will also be backing up the data frequently to ensure that we maintain data integrity. There is always a chance that data can become corrupted, or a problem will arise with it and we want to have a solution for this. By backing up the data, we will easily be able to restore it when something like this happens. This will make data recovery easier and will stop us from losing data in these events while also improving the integrity of the data.

## 5. UI, USER AND TESTING

### 5.1 Registration & Login:

When a user first opens the application, they will be presented with the log in page. If the user has an account and knows their password then they can simply input their details and click the ‘LOGIN’ button, which will take them to the main functionality of the app.

If it is there first time using the app they will need to create an account, they can do this by clicking the ‘Sign Up’ button at the bottom of the page. Doing this will take them to the Create Account page where they can fill in their personal details and then submit them using the ‘Register’ button.

The buttons on these pages are easy for the user to understand they are clickable by making them blue. The icons to the left when entering details will be helpful to make it obvious what needs to be input even if the user does not know English.

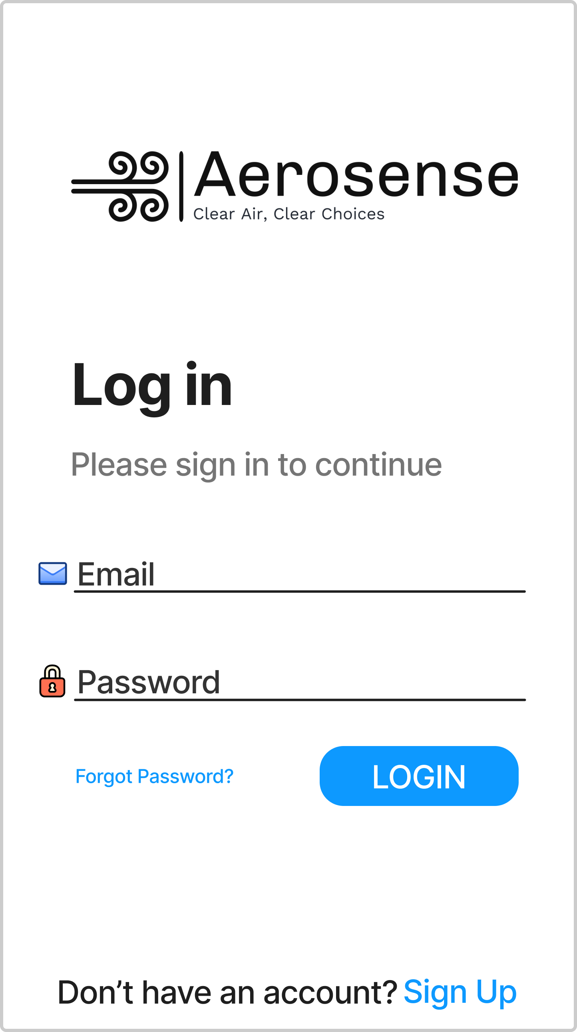
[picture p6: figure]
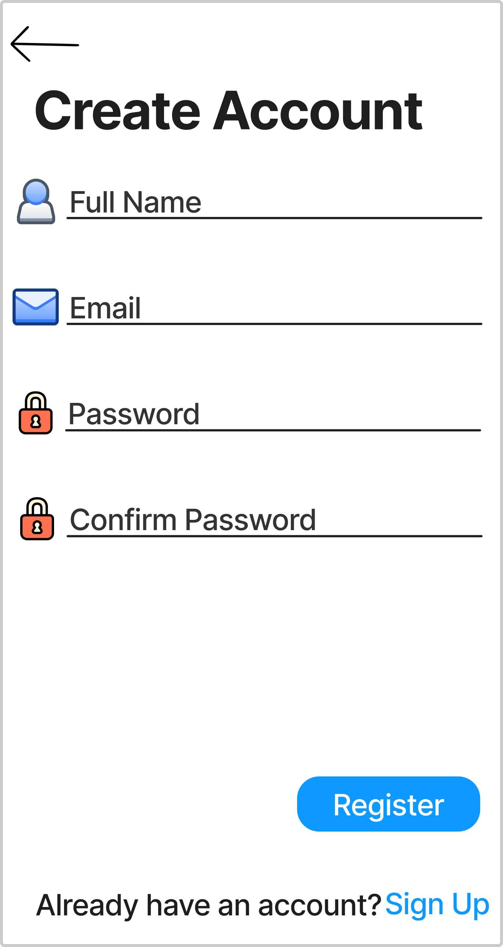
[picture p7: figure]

Diagram 3: User Registration and Login Page Design

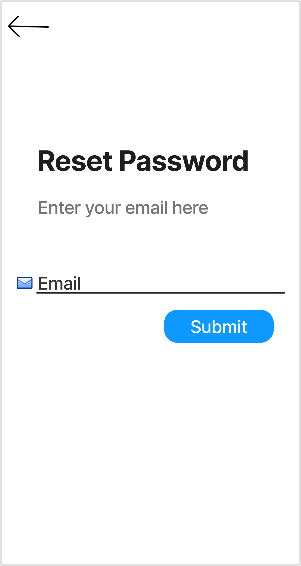
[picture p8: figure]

If the user has account but cannot remember their password, they can then click the ‘Forgot Password’ button on the login page. This will take them to the Reset password page where they can enter the email they previously signed up with and hit submit. This will send an email to the account where they can set a new password for the account.

Diagram 4: Reset Password Page Design

### 5.2 Home Screen & Menu

Diagram 5: Home Screen Page Design

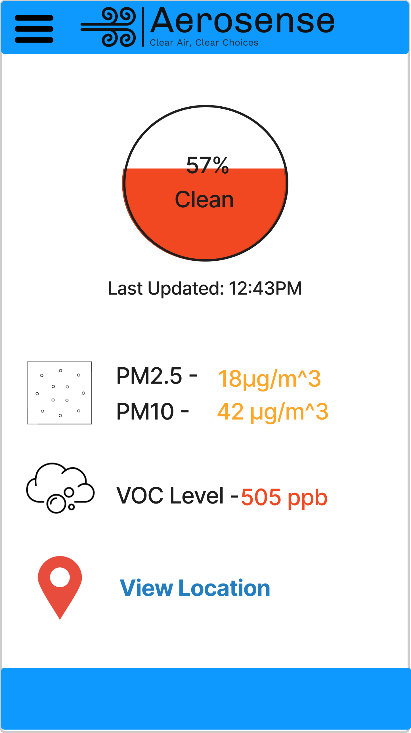
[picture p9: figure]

Whenever a user is signed in and opens the app they will be shown the home screen. This page displays all the important data gathered by the wristband device in a neat and clear manner that is easy for any user to understand. At the top there is a circle that fills up with a certain colour depending on how bad the air quality is in the user’s current location. If the air quality is bad it will display red, if it is moderate it will display yellow and if the air is clean it will be green. This colour coding along with the air quality being displayed as a whole number percentage makes it simple for the user to instantly understand if the air quality is bad or not.

Underneath the circle is more technical data such as Particle Matter data and VOC Level. The colour coding on the values of these data means the user does not need to actually know what they mean but can tell if the levels are dangerous or not by the colour being red or orange. The icons also help illustrate what the data is conveying. At the bottom of the page the user can also click to view their location on a map.

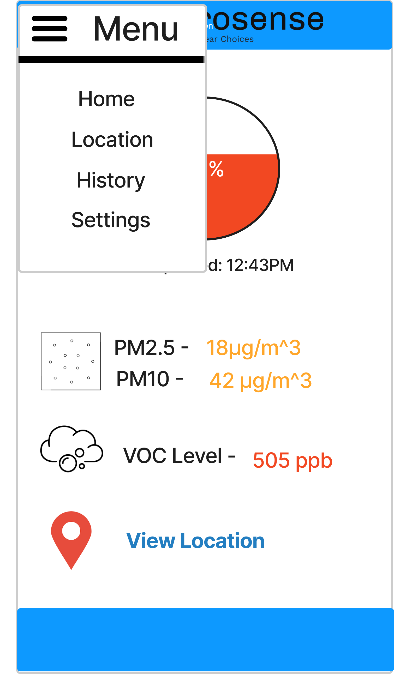
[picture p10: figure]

In the top left of the app there is a menu beutton, this is displayed on all main pages of the app. The hamburger menu icon is a uiversaly understood so any user will know what the button is for. When clicked a dropdown menu will appear with a list of the different pages on the app, this allows the user to quickly switch between different pages for all their information.

Diagram 6: Menu Navigation Page Design

### 5.3 Location & History

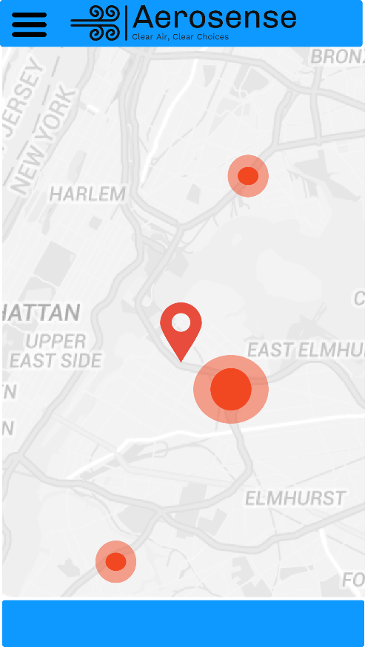
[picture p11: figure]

On the location page, the user is presented with a map of their current location. From here, they can view nearby areas where air quality is at a hazardous level for them. They can tell where they are from the pin on the map and where the hazardous areas are from the red circles, indicating danger.

On this page you will also be able to swipe around and zoom out to see a wider area, user’s will be able to plan ahead on what route they take and can avoid the hazardous air quality, when they are for example going for a run or walk.

Diagram 7: Location Display Page Design

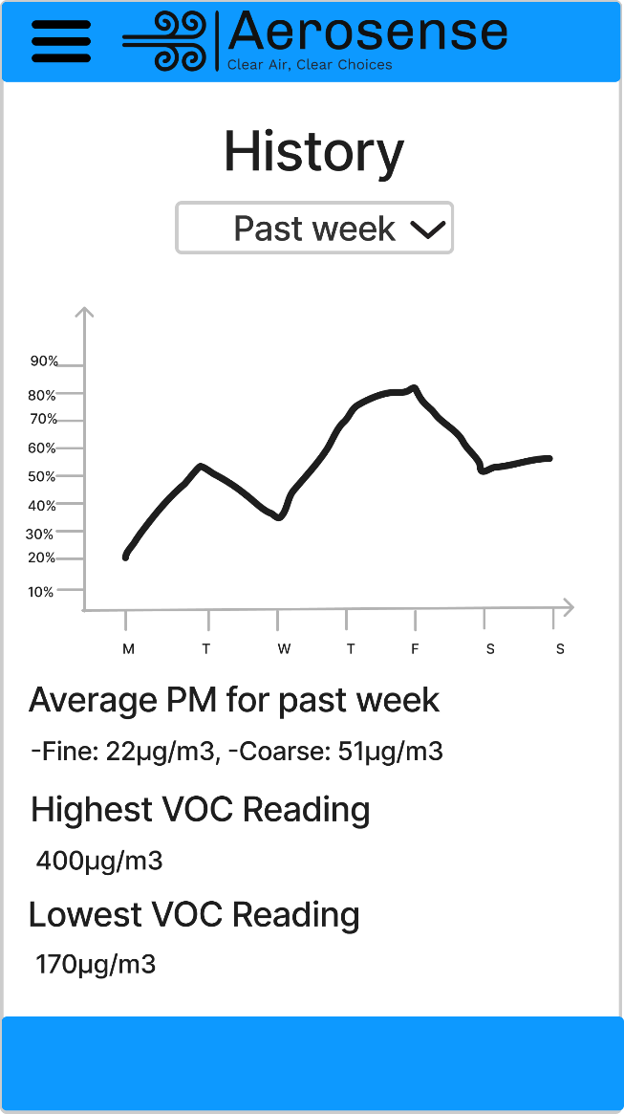
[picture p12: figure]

On the history page, the user will be able to view detailed statistics regarding the data they have collected while wearing their wristband. There is a dropdown menu to select the duration of time they want to view data from, such as past week, month or day.

The graph below this displays the average air quality the user has been exposed to whilst wearing the band over this period of time. On the left of the graph is the percentages of air quality cleanliness and along the bottom are periods in time, in this example we have each day of the week.

This graph simply outlines how clean the air quality they have been surrounded with is and lets the user know if their percentage is high on a certain day or time, they should try to avoid the location they were at that time

Below the graph, we also have average particle matter as well as highest and lowest VOC readings for the period selected.

Diagram 8: History and Past Data Page Design

### 5.4 Settings:

The settings page displays numerous settings in a clear and concise matter. Icons are used to signify to the user what they are for. The pair device button is used to connect the device to the wristband and once connected the user will be able to tell from the connection status to the right of it.

The battery level is shown for the wristband device so the user knows if it needs to be charged or not. If it does go low during use however, an alert will be sent to the user.

The vibration setting can be clicked on and off and the volume level for alerts can be selected by dragging the sound bar higher or lower. When these options are selected, they will also be tested to let the user know what they have chosen, for example when vibration is turned on the band will vibrate and when the sound is selected an alert will play at that volume.

The notification frequency setting includes a dropdown menu for a list of multiple options such as always, only when critical and never.

The user can also change their password from this page in case they are signed in but are not sure what their password is.

There are also colour-coded buttons on the page. The red buttons are for logging out of the application and resetting the changed settings. While the green save button is for saving the changed settings. These colours help the user understand what the buttons might be for.

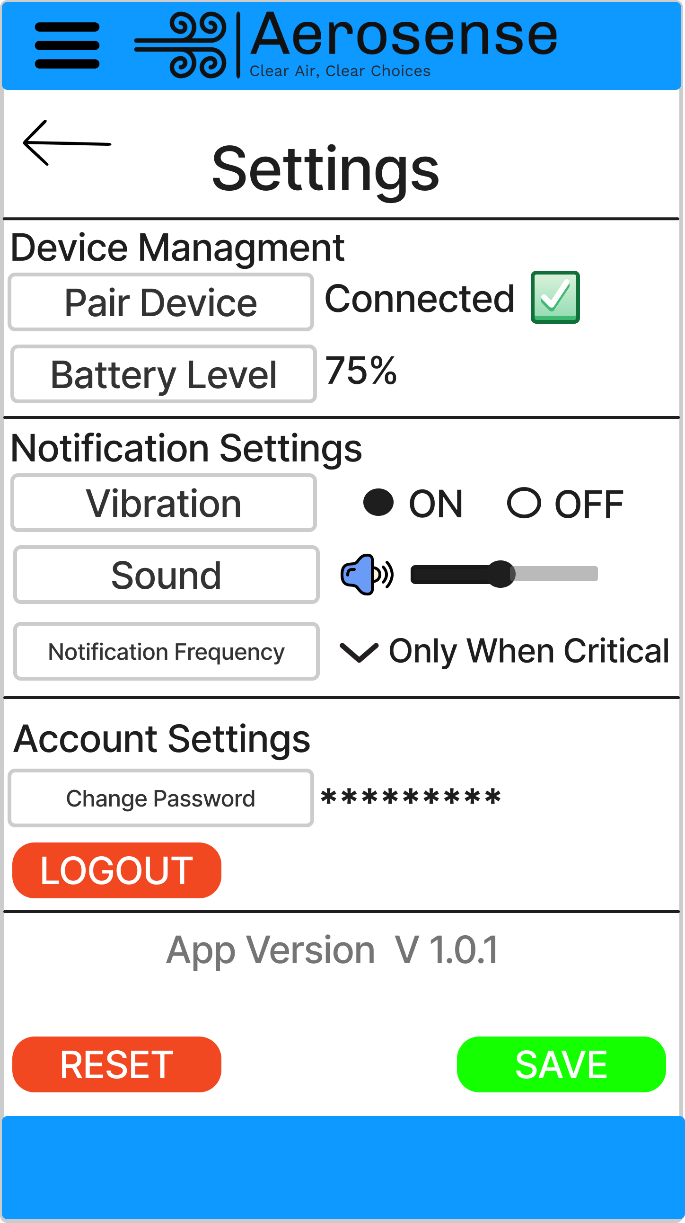
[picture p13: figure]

Diagram 9: User Settings and Configuration Page Design

## 6 USER & TESTING:

This device is for people with asthma, as such this means the user interface needs to be simple and intuitive to use. This way even if the user is panicked or just need to quickly look at the app to understand the data displayed on it they should instantly be able to.

What will determine if this device is successful or not is if people with asthma can use it to track the air quality in their current location and use that information to tell if it is dangerous or not for them to stay or if they should move. They should also be able to view nearby locations and see where the air quality is bad so they know to avoid these areas.

We will test this device by bringing it to areas of varying air quality to test that it properly alerts the user of the air quality in their current location and whether or not it is hazardous for them.

## CONCLUSION

The project's primary goal was to provide a user-friendly device capable of monitoring air quality in real-time, specifically tailored to Ireland's air quality standards. From selecting the appropriate hardware components to setting up the database, was essential. Fritzing diagrams, database schema, and UI designs became our roadmap, guiding each step. Ensuring seamless integration of various sensors with the Pi, balancing between real-time data processing , and designing an intuitive user interface required iterative testing and feedback. The choice of algorithms for computing the Air Quality Index (AQI).

In this report, we detailed the development of Aerosense, an air quality monitor band. We explored the hardware and software components, from integrating sensors to designing the user interface.

## REFERENCES:

- Information on the PMS7003 sensor [Accessed: 21/10/23 14:57] :https://download.kamami.pl/p564008-PMS7003%20series%20data%20manua_English_V2.5.pdf
- Information on the BME680 sensor[Accessed: 21/10/23 15:34]: https://www.bosch-sensortec.com/products/environmental-sensors/gas-sensors/bme680/
- Information on the Air530 sensor[Accessed: 22/10/23 11:29]: https://wiki.seeedstudio.com/Grove-GPS-Air530/
- Data Protection, in transit & at rest [Accessed: 22/10/23 12:24]: https://www.digitalguardian.com/blog/data-protection-data-in-transit-vs-data-at-rest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,contents%20of%20data%20in%20transit.
- Data Protection Information [Accessed: 22/10/23 13:43]: https://www.dataprotection.ie/en/organisations/know-your-obligations/data-security-guidance

WRISTBAND AIR QUALITY MONITOR – VERSION 1

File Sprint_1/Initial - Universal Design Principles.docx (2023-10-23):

Universal Design Principles for the Optimal Workout Band

1. Equitable Use

- We've taken into consideration individuals who are left out by main fitness gadgets, such as those with asthma or cardiac. The Optimal Workout Band is all about inclusivity. We've crafted a device that doesn't leave anyone behind, no matter their health condition or ability.

2. Flexibility in Use

- We recognize that every individual's journey is different. The Optimal Workout Band offers versatility in its alerts, workout settings, and modes. So, whether it's Alex who's asthmatic, John juggling diabetes, or Sarah keeping an eye on her heart, everyone has a tool that resonates with their unique journey.

3. Simple and Intuitive Use

- Tech should be a tool, not a challenge. Acknowledging that not everyone is a tech wizard (like our friend John), we've streamlined the band's interface. The goal? To let folks focus on their fitness instead of fiddling with settings.

4. Perceptible Information

- Fitness environments can be diverse. Be it the chatter in a gym where Alex trains or the bustling park where Sarah jogs; the band ensures crucial alerts don't get lost in the noise. Vibrations, visual cues, or sounds — we've got it all to keep users in the loop.

5. Tolerance for Error

- We're all human, and mistakes happen. We've designed the band with this in mind. Say John accidentally hits the wrong button; the device gently nudges him back on track or reverts to a safe default. No fuss, no stress.

6. Low Physical Effort

- Fitness is challenging enough; your tracker shouldn't add to it. Keeping in mind active users and those with health challenges, we've focused on crafting a comfy, unintrusive band. It's smooth sailing, be it during a push-up or a simple settings check.

7. Size and Space for Approach and Use

- One size doesn't fit all. Our band accommodates various wrist dimensions, ensuring snug yet comfortable fits. Plus, we've been thoughtful about our UI elements. So even users like John, who aren't fans of tiny buttons, find the experience smooth and efficient.

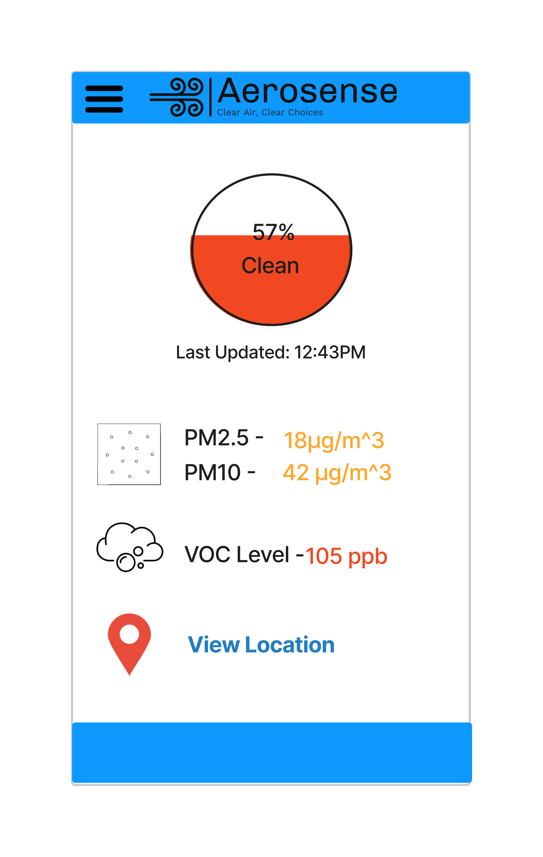
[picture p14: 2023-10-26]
Sprint_4/Paper Prototype/Statistics.png

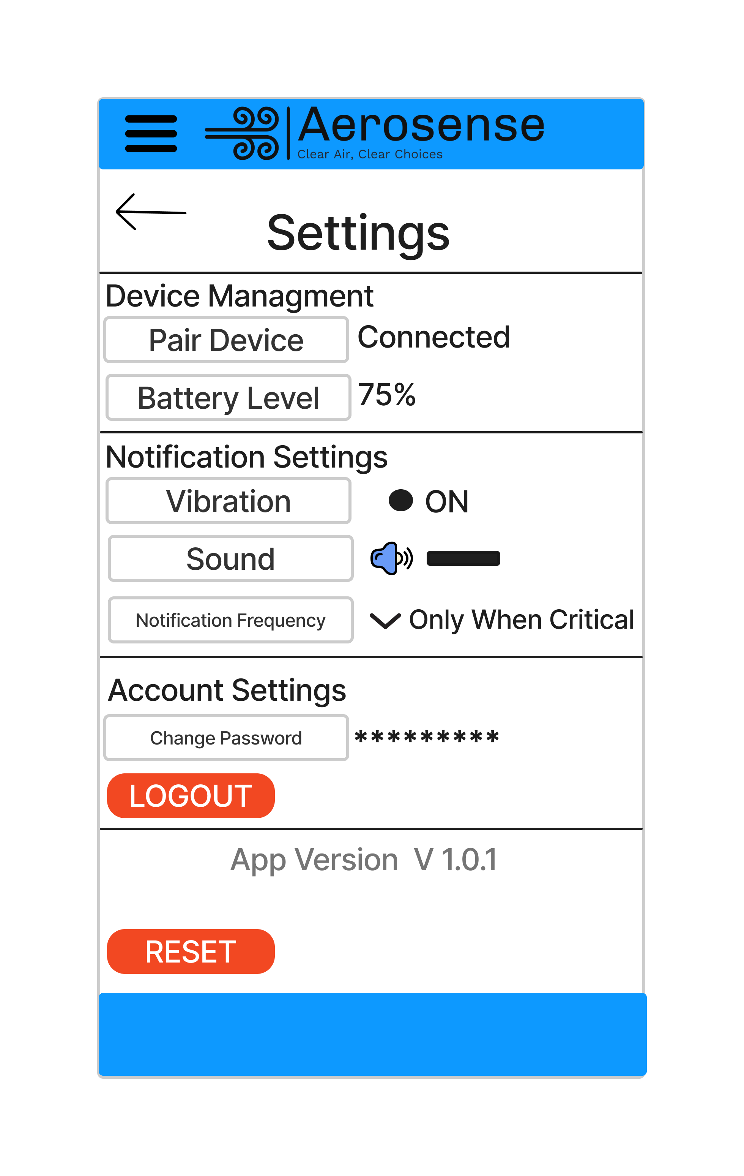
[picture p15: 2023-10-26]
Sprint_4/Paper Prototype/Settings.png

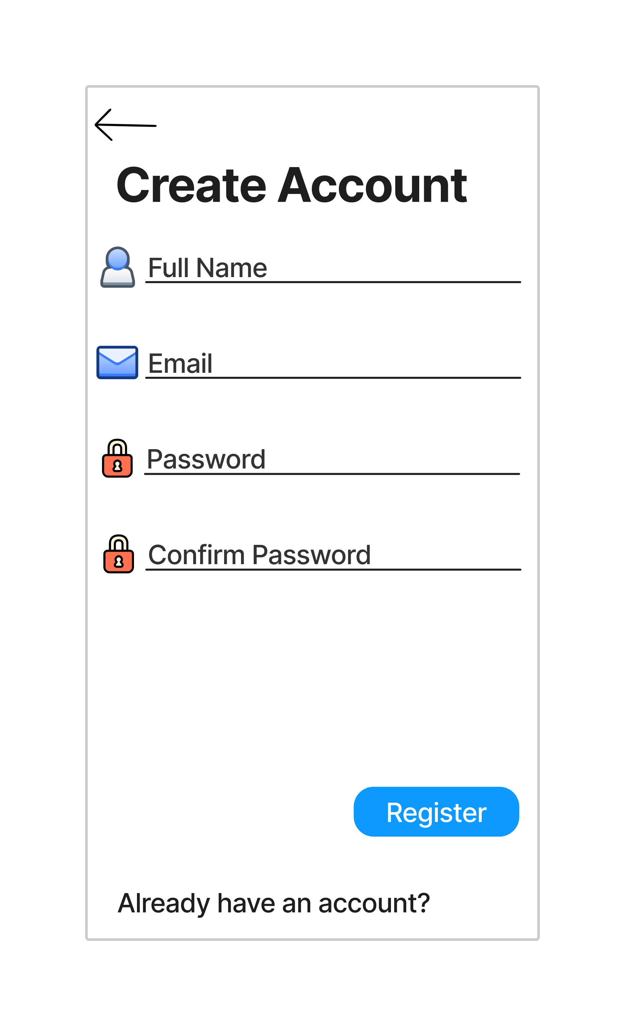
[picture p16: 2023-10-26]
Sprint_4/Paper Prototype/Create_Account.png

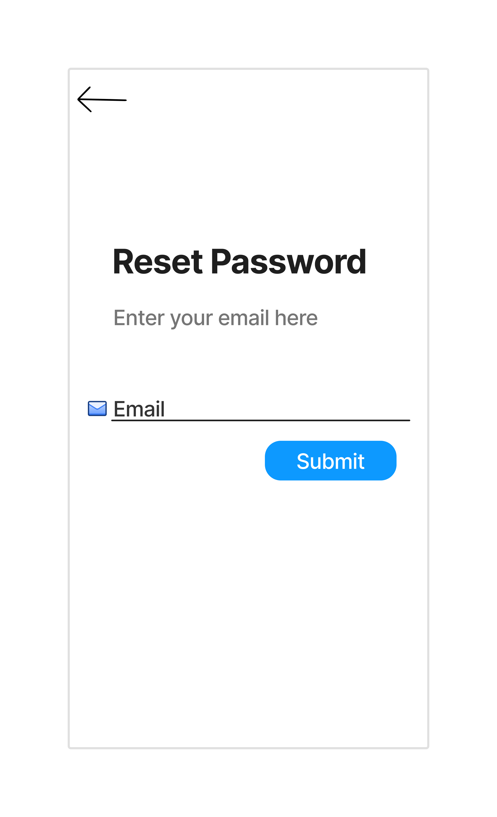
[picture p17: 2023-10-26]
Sprint_4/Paper Prototype/Reset_Password.png

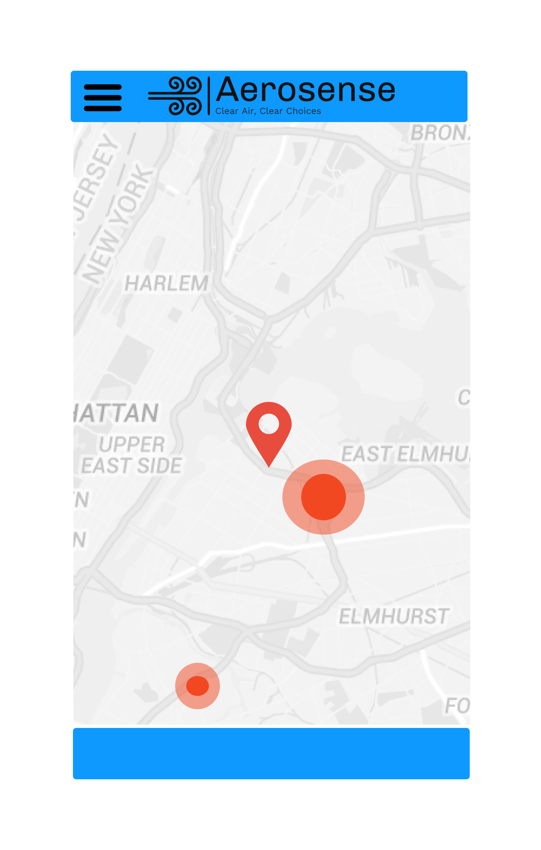
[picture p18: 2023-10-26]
Sprint_4/Paper Prototype/Location.png

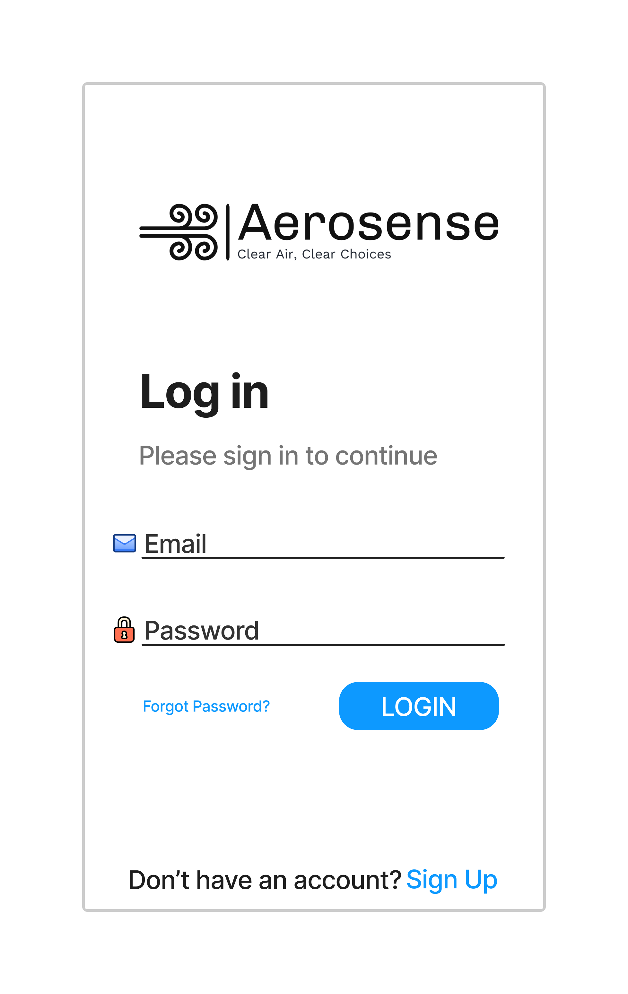
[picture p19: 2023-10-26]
Sprint_4/Paper Prototype/Login.png

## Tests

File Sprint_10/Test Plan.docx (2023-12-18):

### Test Plan

### Objectives of The UI Evaluation

Usability:

- Ease of navigation between different screens.
- Clarity of the information displayed.
- Responsiveness of the app to user interaction.

Functionality:

- Accuracy of the login process.
- Correct display of air quality data.
- Proper functioning of the "View More/Less" feature for detailed air quality data.
- Effectiveness of the educational material in conveying information.
- User profile management, including main asthma trigger and asthma severity levels.
- Accuracy and update frequency of the location mapping for poor air quality areas.
- History page's data representation and time frame selection.
- Notifications: reliability, relevance, and clarity of air quality alerts.
- Settings: ability to manage device connection and notification preferences.

Test Cases For the Screens Login Screen:

- Attempt to login with correct and incorrect credentials.
- Check feedback for invalid login attempts.

Home Screen:

- Verify the air quality percentage updates in real-time.
- Check for the presence and accuracy of PM2.5, PM10, and VOC levels.
- Test "View More/Less" functionality for additional measurements.

Education Page:

- Assess the readability of the content explaining air quality measurements.
- Test any interactive elements like "Read more".

Asthma Profile Page:

- Test for the correct saving and updating of user's main triggers and asthma severity levels.

Location Page:

- Ensure the map loads correctly and displays historical bad air quality markers.
- Test the responsiveness of the map to user inputs, such as zooming and panning.

History Page:

- Verify that weekly air quality history is displayed and can be toggled between "This Week" and "Last Week."
- Check that the average scores and values are correctly calculated.

Notifications Page:

- Confirm that notifications are listed in chronological order.
- Test the display of the heading and message for accuracy and completeness.

Settings Page:

- Test the device management section for pairing and connectivity status.
- Toggle notification settings, specifically the sound option, and observe changes.
- Use the logout button and verify that it logs out the user correctly.

### Objectives for User Evaluation:

- Effectiveness: How well does the app help users in monitoring air quality and managing asthma?
- Efficiency: How quickly can users perform tasks such as checking air quality history, viewing notifications, and updating their asthma profile?
- Satisfaction: How pleased are users with the app's features, design, and overall experience?
- Learnability: How easy is it for new users to understand how to use the app and navigate its features?
- Memorability: After using the app, how easily can users remember how to use it without assistance?
- Error Frequency and Severity: How often do users make errors, how severe are these errors, and how easily can they recover from them?

User Evaluation Test Cases:

First Impressions:

- Record initial reactions upon opening the app for the first time.
- Assess how the login and account setup processes are.

Daily Usage:

- Ask users to perform daily tasks such as checking air quality, updating profiles, and setting notification preferences.
- Observe and record any difficulties or errors encountered during these tasks.

Notification Clarity:

- Evaluate if the notifications provide clear, actionable information.
- Assess if users understand what to do when they receive a notification of poor air quality.

Information Comprehension:

- Test the users understanding of the education page.
- Users will be asked to explain what PM2.5 and PM10 to gauge the clarity of the information.

User Feedback:

- Conduct interviews to collect user feedback on various aspects of the app.

Error Monitoring:

- Record any errors users encounter and how they resolve them.

Accessibility Check:

- Ensure that users with different abilities can use the app comfortably.
- Check for font sizes, color contrasts.

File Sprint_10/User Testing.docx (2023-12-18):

User Testing

Process:

I gathered 2 of my friends to test the system and had a session with them separately for me to receive feedback on the application. I sat them down and gave them a very brief outline of what the app is and who it’s for, so something along the lines of “This is AeroSense, which is a portable air quality monitoring system for people with asthma”. I also quickly informed them of why someone with asthma would need an air quality monitoring system. I then showed them what the portable hub would look like so that they had an idea of how it would be and then I gave them my phone with the app open. I told them to keep in mind who the app is made for and to think aloud while using the app so that I could get their ideas about the user interface and understanding of the application as a first-time user. After that, I sat back in silence and just let them go through the app while writing down any feedback they provided (positive and negative). At the end of the session, I asked them some questions if I felt I needed more insight from them.

Session 1:

Age: 21

Personal experience with Asthma: None

Feedback:

- The login and register pages are simple and clear.
- Could be clearer for the user if we showed the actual parameters for the overall air quality percentage somewhere in the app (e.g. 60% - 100% = good, 40 – 50% = Medium etc.)
- Provide baselines/averages for each measurement so the user can know how much worse or better the measurement is compared to how it should be.
- The extra measurements in the “View More” section of the home page have no comparisons/ways to tell if they are good or bad.
- Add a screen where you can see all notifications received about air quality so that you can look back on recommendations given by them.
- Find a way to show the time for each bad air quality area being marked on the map on the locations page so that the user of the app can know how long ago it was detected as it may be cleared a few hours after that.

Questions asked:

Q: Do you have any feedback on the overall look and feel of the user interface?

A: Overall, it looked and felt clean to use but there are some parts that could have been clearer, especially with the meaning of numbers on the home page.

Q: How useful do you think this system would be to someone with asthma?

A: From their knowledge of asthma, they think that it could prove useful to a lot of people with asthma who go out a lot and maybe go on walks or runs often.

Session 2:

Age: 23

Personal experience with asthma: Father has asthma, so they have a decent amount of experience with it.

Feedback:

- The name and logo suit the app well and the logo looks nice.
- The colours on the home page are a good way of showing air quality.
- The home page is laid out in a nice and clear way.
- We should add some sort of status signifier for numbers at the bottom of the home page to signify whether they are good or bad.
- For the user asthma page, we should add in a wider variety of options for main trigger or allow the user to enter one themselves since there are a lot more things that can trigger asthma other than what we have there. For example, their dad’s asthma can often grow worse when he is around pets, and we don’t have an option there for that.
- Would be nice if we added an option to the history page to view previous weeks data so that the person can look back on it.
- Educational page is very useful and informative.

Questions asked:

Q: Were you already aware of how much air quality has an affect on people with asthma and if so, what does your dad currently do to control this?

A: Yes, they were aware to an extent that air quality plays a part in affecting people’s asthma which is why they have air purifiers around their house in the places he spends the most time such as the sitting room and his bedroom.

Q: Do you think this system would be useful to someone like your dad?

A: They said that they think it would benefit their dad so that he could keep an eye on the air quality at home and also at work since he has an office job and sits in the one place most the time and he could stay aware if the air quality happens to drop.

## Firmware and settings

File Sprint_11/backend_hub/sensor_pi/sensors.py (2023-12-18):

import bme680
import serial
import struct
import time
import RPi.GPIO as GPIO
from pubnub.callbacks import SubscribeCallback
from pubnub.pubnub import PubNub
from pubnub.pnconfiguration import PNConfiguration
from dotenv import load_dotenv
import os

# Load environment variables
load_dotenv()

# Initialize PubNub
pnconfig = PNConfiguration()
pnconfig.subscribe_key = os.getenv('PUBNUB_SUBSCRIBE_KEY')
pnconfig.publish_key = os.getenv('PUBNUB_PUBLISH_KEY')
pnconfig.user_id = "aerosense-model-T5"
pnconfig.cipher_key = os.getenv('PUBNUB_CIPHER_KEY')
pubnub = PubNub(pnconfig)

BUZZER_ACTIVE = True

# GPIO setup
LED_PIN = 16
BUZZER_PIN = 24
GPIO.setmode(GPIO.BCM)
GPIO.setup(LED_PIN, GPIO.OUT)
GPIO.setup(BUZZER_PIN, GPIO.OUT)

# BME680 setup
sensor_bme680 = bme680.BME680(bme680.I2C_ADDR_PRIMARY)
sensor_bme680.set_humidity_oversample(bme680.OS_2X)
sensor_bme680.set_pressure_oversample(bme680.OS_4X)
sensor_bme680.set_temperature_oversample(bme680.OS_8X)
sensor_bme680.set_filter(bme680.FILTER_SIZE_3)
sensor_bme680.set_gas_status(bme680.ENABLE_GAS_MEAS)
sensor_bme680.set_gas_heater_temperature(320)
sensor_bme680.set_gas_heater_duration(150)
sensor_bme680.select_gas_heater_profile(0)

# PMS7003 setup
SERIAL_PORT_PMS7003 = '/dev/ttyUSB0'
ser_pms7003 = serial.Serial(SERIAL_PORT_PMS7003, baudrate=9600, timeout=1)

# GPS setup
SERIAL_PORT_GPS = '/dev/ttyS0'
ser_gps = serial.Serial(SERIAL_PORT_GPS, baudrate=9600, timeout=1)

# Thresholds
TEMP_THRESHOLD = 30
HUMIDITY_THRESHOLD = 57
GAS_THRESHOLD  = 10000
PM_2_5_THRESHOLD = 12
PM_10_THRESHOLD = 54

# Function to parse PMS7003 sensor data
def parse_pms7003_data(data):
    if len(data) == 32 and data[0] == 0x42 and data[1] == 0x4d:
        frame = struct.unpack('>HHHHHHHHHHHHHH', data[4:])
        pm1_0_cf1 = frame[0]
        pm2_5_cf1 = frame[1]
        pm10_cf1 = frame[2]
        pm1_0_atm = frame[3]
        pm2_5_atm = frame[4]
        pm10_atm = frame[5]
        return pm1_0_cf1, pm2_5_cf1, pm10_cf1, pm1_0_atm, pm2_5_atm, pm10_atm
    else:
        return None
    
# Function to parse GNGGA or GPRMC sentences for latitude and longitude
def parse_gps_data(data):
    parts = data.split(',')
    
    if data.startswith('$GNGGA') or data.startswith('$GPRMC'):
        latitude = parts[2]
        longitude = parts[4]
        
        if latitude and longitude:
            # Convert to decimal degrees
            lat_deg = float(latitude[:2])
            lat_min = float(latitude[2:])
            lon_deg = float(longitude[:3])
            lon_min = float(longitude[3:])

            lat = lat_deg + (lat_min/60.0)
            lon = lon_deg + (lon_min/60.0)

            if parts[3] == 'S':
                lat = -lat
            if parts[5] == 'W':
                lon = -lon

            return lat, lon
    return None

def get_gps_data(serial_port, timeout=60):
    start_time = time.time()
    while True:
        elapsed_time = time.time() - start_time
        if elapsed_time > timeout:
            print("GPS timeout reached. No valid data.")
            return None, None
        gps_data = serial_port.readline().decode('utf-8').strip()
        if gps_data:
            gps_parsed = parse_gps_data(gps_data)
            if gps_parsed:
                print(f"GPS Data Acquired: Latitude: {gps_parsed[0]}, Longitude: {gps_parsed[1]}")
                return gps_parsed
        time.sleep(0.5) 

# PubNub callback class
class MySubscribeCallback(SubscribeCallback):
    def message(self, pubnub, message):
        global BUZZER_ACTIVE
        if 'sound' in message.message:
            BUZZER_ACTIVE = message.message['sound']

# Register PubNub listener
pubnub.add_listener(MySubscribeCallback())
pubnub.subscribe().channels('user_settings_channel').execute()

def beep(repeat):
    if BUZZER_ACTIVE:
        for _ in range(repeat):
            for pulse in range(60):
                GPIO.output(BUZZER_PIN, True)
                time.sleep(0.001)
                GPIO.output(BUZZER_PIN, False)
                time.sleep(0.001)
            time.sleep(0.02)

def trigger_alert():
    beep(5)
    # Blink LED 5 times
    for _ in range(5):
        GPIO.output(LED_PIN, GPIO.HIGH)
        time.sleep(0.5)
        GPIO.output(LED_PIN, GPIO.LOW)
        time.sleep(0.5)

def check_air_quality(temp, humidity, gas_resistance, pm2_5, pm10):
    if (temp > TEMP_THRESHOLD or humidity > HUMIDITY_THRESHOLD or
        gas_resistance < GAS_THRESHOLD or pm2_5 > PM_2_5_THRESHOLD or
        pm10 > PM_10_THRESHOLD):
        return True
    return False

def my_publish_callback(envelope, status):
    # Handle publish response
    if not status.is_error():
        print("Message published successfully")
    else:
        print("Error in publishing message")

def main():
    try:
        while True:
            # Initialize the variables with default values
            temp = None
            humidity = None
            gas_resistance = None
            voc_level = None
            pm2_5 = None
            pm10 = None
            lat = None
            lon = None

            # Attempt to read from BME680 sensor
            if sensor_bme680.get_sensor_data():
                temp = sensor_bme680.data.temperature
                humidity = sensor_bme680.data.humidity
                gas_resistance = sensor_bme680.data.gas_resistance
                voc_level = GAS_THRESHOLD / gas_resistance

            # Read from PMS7003 sensor
            data = ser_pms7003.read(32)
            if data:
                pms_data = parse_pms7003_data(data)
                if pms_data:
                    pm2_5, pm10 = pms_data[1], pms_data[2]

            # Check air quality before attempting to read GPS
            if None not in [temp, humidity, gas_resistance, pm2_5, pm10]:
                if check_air_quality(temp, humidity, gas_resistance, pm2_5, pm10):
                    print("Poor air quality detected, waiting for GPS data.")
                    lat, lon = get_gps_data(ser_gps)

                    if lat is not None and lon is not None:
                        print(f"GPS Data: Latitude: {lat}, Longitude: {lon}")
                        # Construct data payload
                        data = {
                            'modelNumber': "T5",
                            'temperature': temp,
                            'humidity': humidity,
                            'gas_resistance': gas_resistance,
                            'voc': voc_level,
                            'pm2_5': pm2_5,
                            'pm10': pm10,
                            'latitude': lat,
                            'longitude': lon
                        }
                    else:
                        print("No GPS data received within the timeout period.")

                    print(f"Data: {data}")
                    trigger_alert()
                    # Publish to PubNub
                    pubnub.publish().channel('aerosense_channel').message(data).pn_async(my_publish_callback)
            else:
                print("Waiting for valid sensor data...")

            time.sleep(1)

    except KeyboardInterrupt:
        ser_pms7003.close()
        ser_gps.close()
        GPIO.cleanup()

if __name__ == "__main__":
    main()

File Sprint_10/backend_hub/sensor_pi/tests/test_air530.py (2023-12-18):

#I couldn't get the data from the gps module
#tried reading documentation and different methods but it didn't work

import serial
import time

def read_gps(serial_port):
    ser = serial.Serial(serial_port, 9600, timeout=0)
    ser.flush()

    while True:
        gps_data = ser.readline().decode('utf-8')
        if gps_data.startswith('$GPGGA'):
            return gps_data
        time.sleep(0.1)

if __name__ == "__main__":
    serial_port = "/dev/ttyAMA0"  #also chnaged it to ttyS0
    while True:
        print(read_gps(serial_port))
        time.sleep(5)

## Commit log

2023-10-22 Add initial system models and roles for sprint_0
    This commit introduces the foundational system models,
    environment details, and team roles required for the
    initial phase (sprint_0) of our UDP project. It aims to
    provide a clear overview and set the stage for subsequent
    sprints. The emphasis has been on ensuring that all
    components and responsibilities are well-defined.
2023-10-23 Created PowerPoint slides for elevator pitch
2023-10-23 Implement use case for supervising health concerns
2023-10-23 Amend project overview
    Revised the project summary to emphasize the wristband's air quality
    tracking tailored for asthma patients
2023-10-23 Add researched sensors and hardware
    Detailed the selected sensors for air quality and location tracking,
    specifically PMS7003, BME680, and Air530, with justifications against
    their alternatives. Also included a breakdown of hardware components
    purchased, ensuring optimal cost-efficiency and performance.
2023-10-24 Add core use case and primary user persona
    Introduced a fundamental use case and detailed a core user persona
    to the project documentation.
2023-10-24 Add database schema for Air Quality Wristband
    - Introduce database schema tailored for wristband functionality.
    - Define entities: User, Wristband, Air Quality Measurement, Location, and Notification.
    - Outline relationships among these entities.
    - Describe detailed table structures for each entity.
    - Discuss considerations behind sensor measurements and storage.
2023-10-24 Add MOSCOW analysis for Wristband Air Quality
    This commit introduces the MOSCOW analysis for the Wristband
    Air Quality Monitor project. The analysis provides a clear
    distinction of feature priorities, ensuring the development
    focus remains on essential features for the asthma patients.
2023-10-26 Digitalised prototype using figma and created presentation slides
2023-11-21 Refactor project scope to Smart Indoor Air Quality Hub
    Recognizing the unique needs of asthma patients and the feedbacks from oue academic lecturers and also the market analysis, we have chansged from being a wristband to a smart indoor air quality hub.
2023-11-21 Update use cases to align with Aerosense Hub's new scope
    We have redefined Aerosense use cases, following the chnages from a wearable device to a smart indoor hub. The use cases covers the daily air quality management, emergency situations and for weekly r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
2023-11-23 Update Figma prototypes
2023-11-24 Upload code done for Sprint 5
    [Hardware Connection.fzz]
2023-11-24 Upload code done for Sprint 6
    [Hardware Connection.fzz]
2023-11-24 Upload code done for sprint 7
    [Hardware Connection.fzz]
2023-11-24 Upload code done for sprint 8
    [Hardware Connection.fzz]
2023-12-18 Upload rest of code for sprint 9
    [Hardware Connection.fzz]
2023-12-18 Upload code for sprint 10
    [Hardware Connection.fzz]
2023-12-18 Upload code and documents for sprint 11
    [Hardware Connection.fzz]
